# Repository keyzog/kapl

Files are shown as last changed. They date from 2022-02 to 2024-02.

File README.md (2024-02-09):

# Kapl Keyboard

The Kapl is a split ergonomic keyboard with 70 keys (7x5).
Please read project wiki for details: https://github.com/keyzog/kapl/wiki

**Detailed assembly instructions:** https://keyzog.com/post/kapl-build-guide (RU)

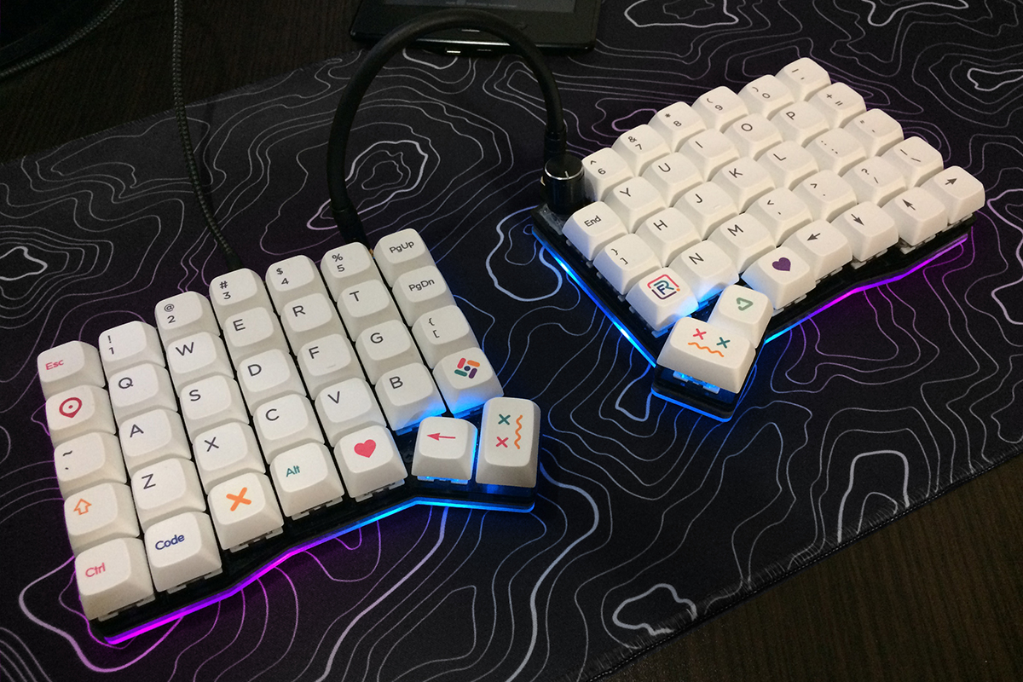
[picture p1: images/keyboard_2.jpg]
Kapl split keyboard

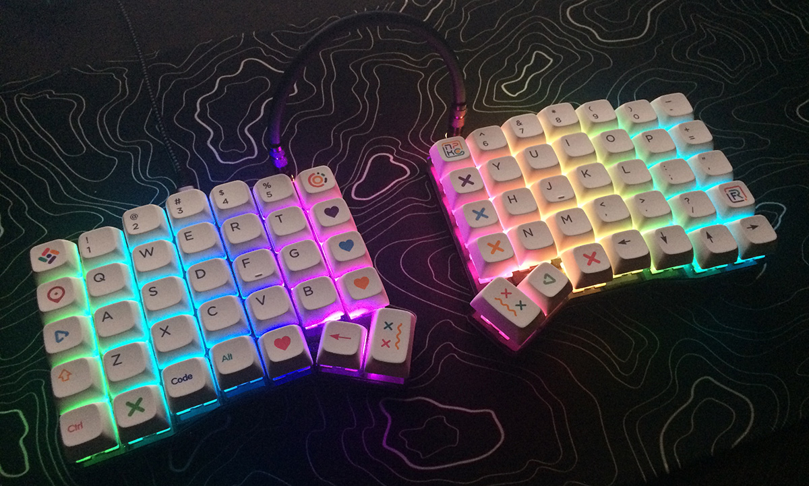
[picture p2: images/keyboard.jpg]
Kapl split keyboard


Board with controller on back side.
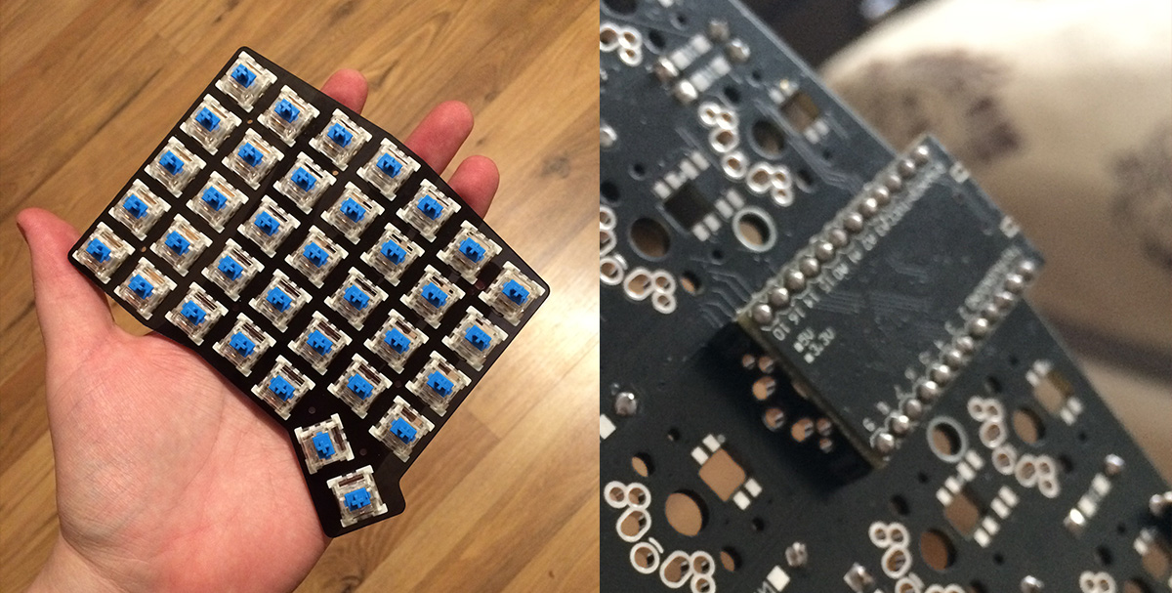
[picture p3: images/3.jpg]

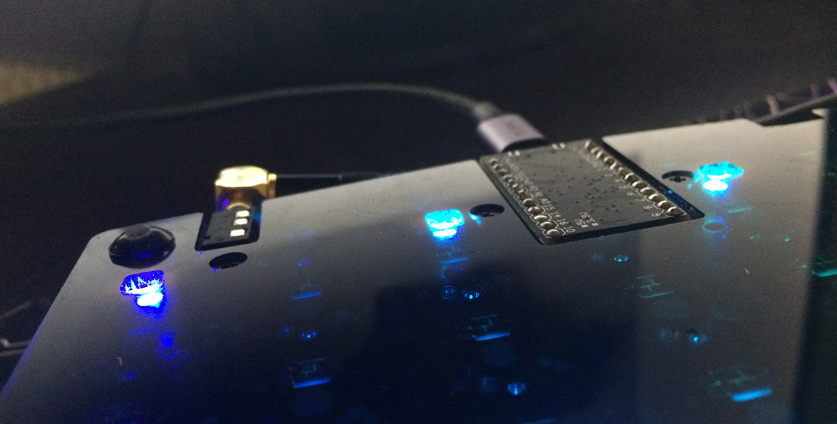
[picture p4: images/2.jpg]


## PCB

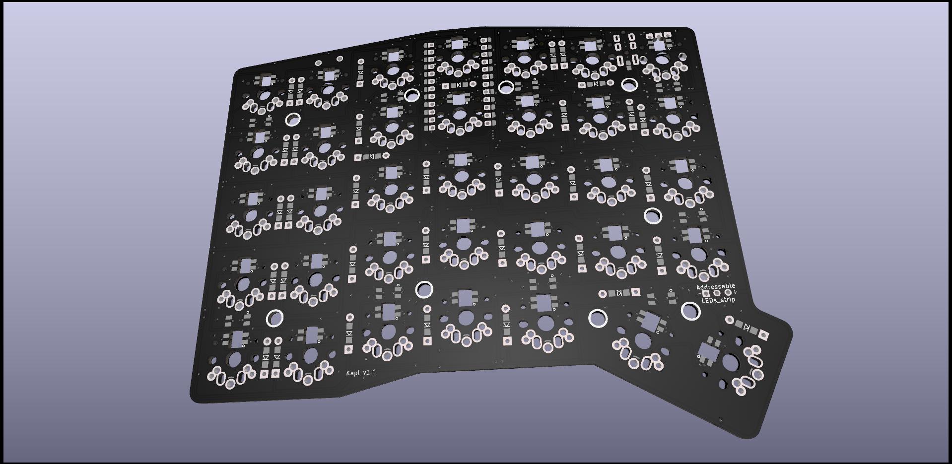
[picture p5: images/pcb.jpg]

[gerbers/gerber\_\_main.zip](https://github.com/keyzog/kapl/raw/main/gerbers/gerber__main.zip)

## Firmware

Kapl uses [QMK firmware](https://qmk.fm/)

## Todo

-  [x] [list of materials](https://github.com/keyzog/kapl/wiki#bill-of-materials)
-  [x] rotation encoder support
-  [ ] building guide
-  [ ] tilting-tenting case

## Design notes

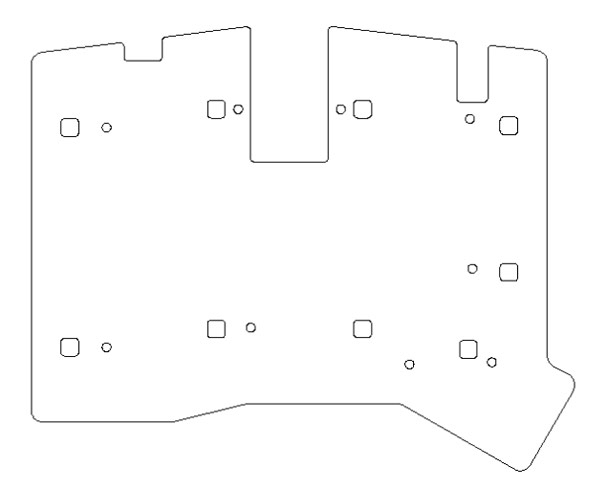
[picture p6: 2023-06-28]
images/case/acrylic/bottom_withLeds_withMKcut.jpg

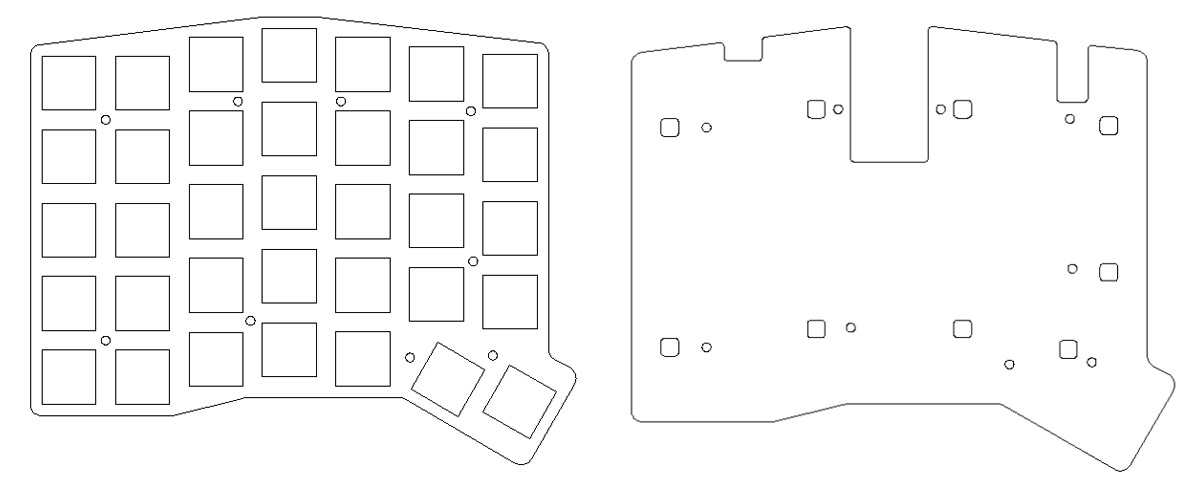
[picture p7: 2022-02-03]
images/case_with_cut.jpg

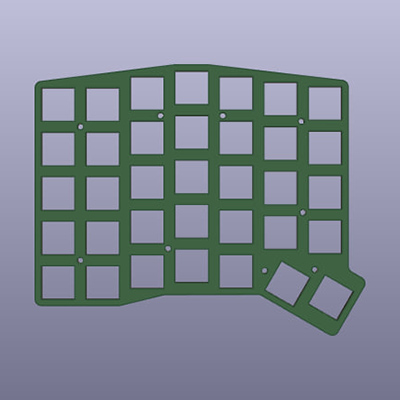
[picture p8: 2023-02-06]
images/case/pcb/top.jpg

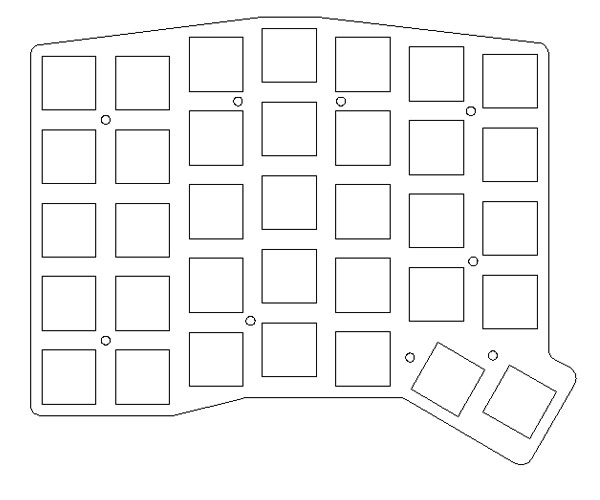
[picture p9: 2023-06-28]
images/case/acrylic/top.jpg

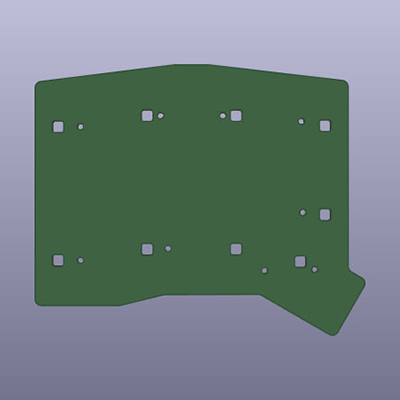
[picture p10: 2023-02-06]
images/case/pcb/bottom_withLeds.jpg

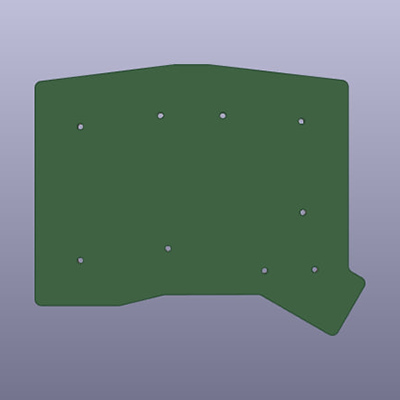
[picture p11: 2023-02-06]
images/case/pcb/bottom.jpg

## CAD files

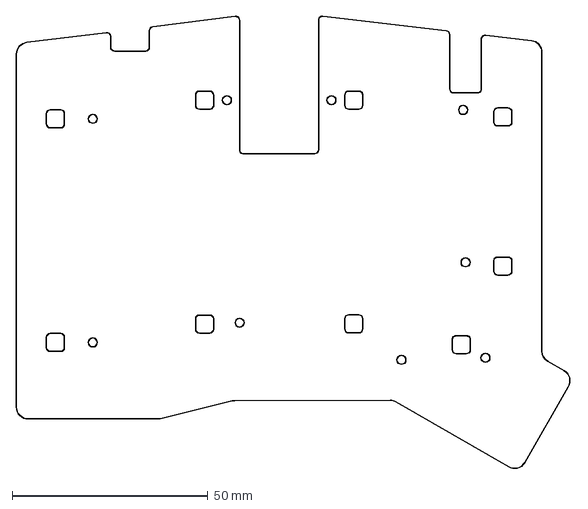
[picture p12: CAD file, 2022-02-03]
case/dxf/bottom_withLeds.dxf
141.9 x 115.7 mm

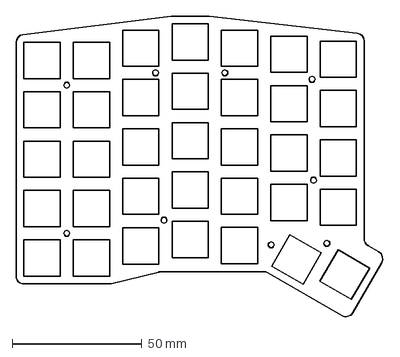
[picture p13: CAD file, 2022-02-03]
case/dxf/top.dxf
141.9 x 116.1 mm

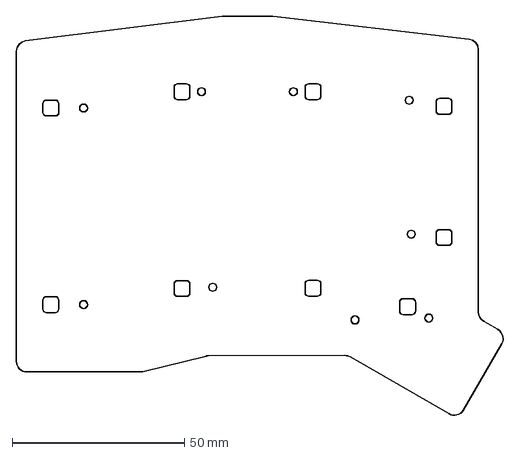
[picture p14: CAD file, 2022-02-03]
case/dxf/bottom_withLeds_withMKcut.dxf
141.9 x 116.1 mm

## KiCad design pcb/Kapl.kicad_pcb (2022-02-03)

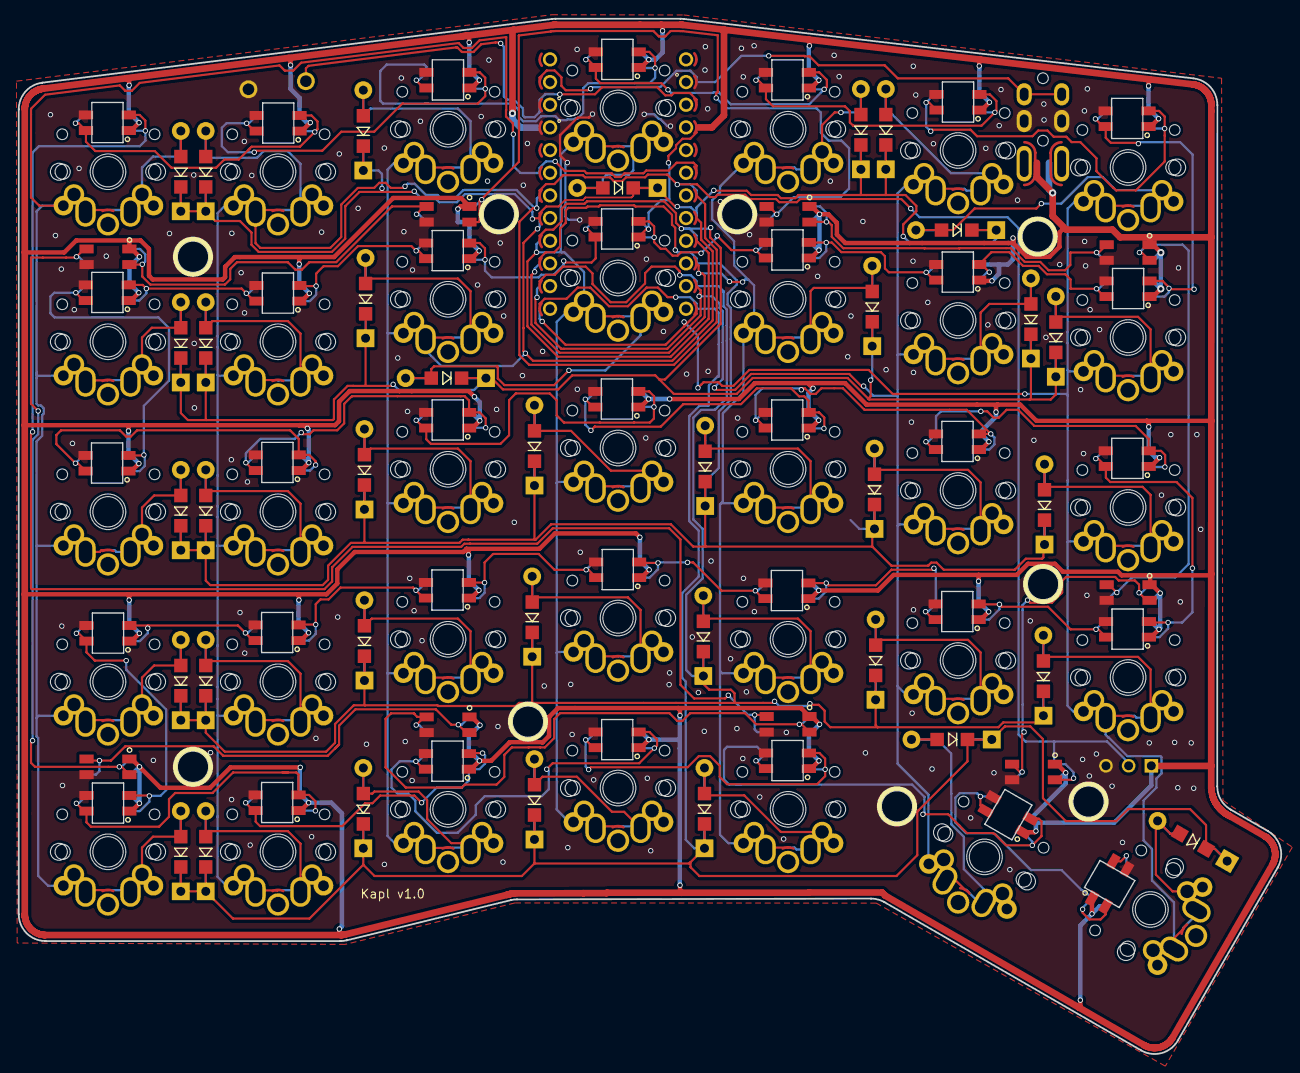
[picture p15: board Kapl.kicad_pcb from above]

Board: 2 copper layers, 141.5 x 116.0 mm, 127 parts (0 on the bottom side), 95 nets.

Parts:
BL1, BL2, BL3, BL4, BL5, BL6, BL7, BL8, BL9: SK6812MINI; SK6812MINI_surface
D1, D2, D3, D4, D5, D6, D7, D8, D9, D10, D11, D12, D13, D14, D15, D16, D17, D18, D19, D20, D21, D22, D23, D24, D25, D26, D27, D28, D29, D30, D31, D32, D33, D34, D35: D; Diode
H1, H2, H3, H4, H5, H6, H7, H8, H9: MountingHole; MountingHole_3.2mm_M3
J1: LED_strip_conector; StripLED_rev
L1, L2, L3, L4, L5, L6, L7, L8, L9, L10, L11, L12, L13, L14, L15, L16, L17, L18, L19, L20, L21, L22, L23, L24, L25, L26, L27, L28, L29, L30, L31, L32, L33, L34, L35: SK6812MINI; SK6812MINI_rev
MJ1: Mini Jack; MJ-4PP-9
RSW1: SW_PUSH; ResetSW
SW1, SW2, SW3, SW4, SW5, SW6, SW7, SW8, SW9, SW10, SW11, SW12, SW13, SW14, SW15, SW16, SW17, SW18, SW19, SW20, SW21, SW22, SW23, SW24, SW25, SW26, SW27, SW28, SW29, SW30, SW31, SW32, SW33, SW34, SW35: SW_PUSH; MX-ALPs-PG1350-rev
U1: ProMicro

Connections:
GND: BL1.2, BL2.2, BL3.2, BL4.2, BL5.2, BL6.2, BL7.2, BL8.2, BL9.2, J1.1, L1.2, L2.2, L3.2, L4.2, L5.2, L6.2, L7.2, L8.2, L9.2, L10.2, L11.2, L12.2, L13.2, L14.2, L15.2, L16.2, L17.2, L18.2, L19.2, L20.2, L21.2, L22.2, L23.2, L24.2, L25.2, L26.2, L27.2, L28.2, L29.2, L30.2, L31.2, L32.2, L33.2, L34.2, L35.2, MJ1.C, RSW1.2, U1.3, U1.4, U1.23
LED: BL1.3, J1.2, U1.7
unnamed: BL1.1, BL2.3
unnamed: BL2.1, BL3.3
unnamed: BL3.1, BL4.3
unnamed: BL4.1, BL5.3
unnamed: BL5.1, BL6.3
unnamed: BL6.1, BL7.3
unnamed: BL7.1, BL8.3
unnamed: BL8.1, BL9.3
unnamed: BL9.1, L1.3
unnamed: D1.2, SW1.2
unnamed: D2.2, SW2.2
unnamed: D3.2, SW3.2
unnamed: D4.2, SW4.2
unnamed: D5.2, SW5.2
unnamed: D6.2, SW6.2
unnamed: D7.2, SW7.2
unnamed: D8.2, SW8.2
unnamed: D9.2, SW9.2
unnamed: D10.2, SW10.2
unnamed: D11.2, SW11.2
unnamed: D12.2, SW12.2
unnamed: D13.2, SW13.2
unnamed: D14.2, SW14.2
unnamed: D15.2, SW15.2
unnamed: D16.2, SW16.2
unnamed: D17.2, SW17.2
unnamed: D18.2, SW18.2
unnamed: D19.2, SW19.2
unnamed: D20.2, SW20.2
unnamed: D21.2, SW21.2
unnamed: D22.2, SW22.2
unnamed: D23.2, SW23.2
unnamed: D24.2, SW24.2
unnamed: D25.2, SW25.2
unnamed: D26.2, SW26.2
unnamed: D27.2, SW27.2
unnamed: D28.2, SW28.2
unnamed: D29.2, SW29.2
unnamed: D30.2, SW30.2
unnamed: D31.2, SW31.2
unnamed: D32.2, SW32.2
unnamed: D33.2, SW33.2
unnamed: D34.2, SW34.2
unnamed: D35.2, SW35.2
unnamed: L1.1, L2.3
unnamed: L2.1, L3.3
unnamed: L3.1, L4.3
unnamed: L4.1, L5.3
unnamed: L5.1, L6.3
unnamed: L6.1, L7.3
unnamed: L8.3, L9.1
unnamed: L9.3, L10.1
unnamed: L10.3, L11.1
unnamed: L11.3, L12.1
unnamed: L12.3, L13.1
unnamed: L13.3, L14.1
unnamed: L7.1, L14.3
unnamed: L15.1, L16.3
unnamed: L8.1, L15.3
unnamed: L16.1, L17.3
unnamed: L17.1, L18.3
unnamed: L18.1, L19.3
unnamed: L19.1, L20.3
unnamed: L20.1, L21.3
unnamed: L21.1, L28.3
unnamed: L22.1, L29.3
unnamed: L22.3, L23.1
unnamed: L23.3, L24.1
unnamed: L24.3, L25.1
unnamed: L25.3, L26.1
unnamed: L26.3, L27.1
unnamed: L27.3, L28.1
unnamed: L29.1, L30.3
unnamed: L30.1, L31.3
unnamed: L31.1, L32.3
unnamed: L32.1, L33.3
unnamed: L33.1, L34.3
unnamed: L34.1, L35.3
VCC: BL1.4, BL2.4, BL3.4, BL4.4, BL5.4, BL6.4, BL7.4, BL8.4, BL9.4, J1.3, L1.4, L2.4, L3.4, L4.4, L5.4, L6.4, L7.4, L8.4, L9.4, L10.4, L11.4, L12.4, L13.4, L14.4, L15.4, L16.4, L17.4, L18.4, L19.4, L20.4, L21.4, L22.4, L23.4, L24.4, L25.4, L26.4, L27.4, L28.4, L29.4, L30.4, L31.4, L32.4, L33.4, L34.4, L35.4, MJ1.D, U1.21
col0: SW1.1, SW8.1, SW15.1, SW22.1, SW29.1, U1.19
col1: SW2.1, SW9.1, SW16.1, SW23.1, SW30.1, U1.18
col2: SW3.1, SW10.1, SW17.1, SW24.1, SW31.1, U1.17
col3: SW4.1, SW11.1, SW18.1, SW25.1, SW32.1, U1.16
col4: SW5.1, SW12.1, SW19.1, SW26.1, SW33.1, U1.15
col5: SW6.1, SW13.1, SW20.1, SW27.1, SW34.1, U1.14
col6: SW7.1, SW14.1, SW21.1, SW28.1, SW35.1, U1.13
data: MJ1.B, U1.2
reset: RSW1.1, U1.22
row0: D1.1, D2.1, D3.1, D4.1, D5.1, D6.1, D7.1, U1.8
row1: D8.1, D9.1, D10.1, D11.1, D12.1, D13.1, D14.1, U1.9
row2: D15.1, D16.1, D17.1, D18.1, D19.1, D20.1, D21.1, U1.10
row3: D22.1, D23.1, D24.1, D25.1, D26.1, D27.1, D28.1, U1.11
row4: D29.1, D30.1, D31.1, D32.1, D33.1, D34.1, D35.1, U1.12

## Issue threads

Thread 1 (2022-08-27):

Cool stuff man, does it support low profile kailh keyswitch?

jmnguye, 2022-08-27:

keyzog, 2022-08-27:
Thank you! Yes it support.

But, keep in mind that spacing between switches is 19.1mm this is MX spacing. This is suitable for most keycaps (lowprofile too). But, if you are going to use MBK keycaps (17.5x16.5mm), then there will be an increased gap between them.

I have a plan make new pcb with spacing for MBK keycaps, but now don't have time for that.

Closed 2023-01-31.

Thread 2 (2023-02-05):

Kailh sockets and recommended version

isavcic, 2023-02-05:
Hello,

Great looking keyboard, thanks for sharing it!

A couple of questions:

- Does the PCB support Kailh hotswap sockets?
- What is the recommended version, the one from the main branch or the revised one?

Thanks!

keyzog, 2023-02-05:
Hello, thanks)
- in now pcb don't support hotswap. I have plan add hotswap, but not before a couple of months.
-  it's better to use the main branch version. I haven't tried soldering version 1.1 yet (pcb_rev branch). You can try it if you want, but at your own risk. But you can safely use [gerber__plate_bottom.zip](https://github.com/keyzog/kapl/blob/pcb_rev/gerbers/gerber__plate_bottom.zip) and [gerber__plate_top.zip](https://github.com/keyzog/kapl/blob/pcb_rev/gerbers/gerber__plate_top.zip) from the pcb_rev branch to create the case.

keyzog, 2023-02-06:
**Remark to previous comment**

Added case pcbs in main branch, should have done it much sooner.
https://github.com/keyzog/kapl/wiki#from-pcb

And moved pcb v1.1 to dev branch, using also at your own risk.

isavcic, 2023-02-11:
Thank you!

Closed 2023-02-11.

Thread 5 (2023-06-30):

how to solder pro micro.

logicalbhanu, 2023-06-30:
Hi, thanks for this great project, i am trying to build it, but being noob in electrical stuff wouldn't be able to figure out how to solder the pro micro, as it is solder on the back of the pcb, with switches on on top it(on front side), can share some pictures of give some suggestion on how to do it.

keyzog, 2023-06-30:
Hello! Hope this helps you: https://imgur.com/gallery/7m69tiw

If you have any questions, you can write to me at the contacts in my profile.

Don't forget to share a photo of the result 😉

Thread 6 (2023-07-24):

no of m2 spacers

logicalbhanu, 2023-07-24:
hi, keyzog
me again(thanks for resolving my last issue), i want to know that in the list of materials you have mentioned the number of spacers as 18, but in the build guides one of the image, i am seeing only 9 spacers, here is the image
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
am i missing something(being a noob in this).

logicalbhanu, 2023-07-26:
thanks mate,my bad i didn't consider the left hand.

Closed 2023-07-26.

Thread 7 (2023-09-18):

what other spacer/standoffs sizes are compatible

logicalbhanu, 2023-09-18:
Hi,
My issue is i am not getting m2 spacer nearby and nor on online at least in my country at good price, can i use m3 spacer or m2.5 spacer, or what are the other options regarding sizes for spacers if possible?

keyzog, 2023-09-20:
Hello!
The size of the hole in the board to accommodate the standoffs is 3.5mm. Only M2 of a standoffs will fit into such a hole.

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

You can save money by using regular M2 bolts and nuts. Just calculate the height of the bolts so that they are not too long. This method is not as convenient compared to racks.

You can also use spacers made of different materials. For example, print on a 3D printer or wrap some [duct tape))](https://live.staticflickr.com/8160/7214525854_733237dd83_z.jpg)

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

Be careful, the very first version of the board had 3.2mm holes; if you ordered the board more than a year ago, you may have this version.

logicalbhanu, 2023-10-22:
i eventually get the m2 spacer/standoff so order it,

but here i am with a new issue and that is, i am try to test the working of some keys before soldering all of them, thus i perform the following tasks:
1. solder all the diodes.
2. flash the pro micros with kapl_v1.hex file given in the link of the repo( i do test my pro connecting two of its pins on opposite sides and they are printing something on my device terminal app).
3. fit all the keys to the top plate and set it with pcb.
4. solder one key among all the keys to test whether it is working or not.

but sadly i am not getting any character when pressing that key, i also tried the reset button and that also seems to be not working( what i am doing is, why reflashing my pro micro rather than shorting the GND and RST pins i am pressing the reset button in the hope that it will start the flash in the qmk toolbox app like it did if shorted the pins directly but nothing is happening there).

i don't know what i am doing wrong so here is the picture of my setup

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

the circled key is the one i have souldered to test the pcb(i order the pcb for jlpcb so i am expecting it of good quality).
so once again can you guide toward any pointer which can help me figure out.

keyzog, 2023-10-22:
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

1) This pin look bad soldered. If the contact is poor, the switches will operate very unstable.
2) You missed one diode.
3) Did you remember to solder the diode under the controller?

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

For just testing pcb you can use tweeters. This is not very convenient, but it is much easier than soldering each switch for testing. https://www.youtube.com/shorts/-FCV9InV3x8

It’s better to write to me in telegram or email, it will be more productive. Contacts are in the profile.

logicalbhanu, 2023-10-23:
thanks again, yes i soldered the diode(it is not visible though because of the pro micro), but yes i do missed the second diode that you pointed out(thanks again), and also thanks for the telegram info it will be much helpfull for me.

Closed 2023-10-23.

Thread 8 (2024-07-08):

Some keys are not working, dunno how to debug

jorgelrezende, 2024-07-08:
Hello, I've finished to assemble on half of my keyboard, but some keys are not working, my question is, all keys only work when the two halfs are assembled together? or each half should work all keys independently?

keyzog, 2024-07-08:
Hello! Some buttons are responsible for switching layers. When you click on them, it may seem that nothing happens, because... Most keyboard testing programs/sites cannot detect such keystrokes.

Below is a screenshot with these buttons:
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

jorgelrezende, 2024-07-08:
right, but all the esc column is not work here on testing, the 5 key and backspace as well, i will try to  verify with a multimeter if all diodes are working, but i dont know what is happening

keyzog, 2024-07-08:
If the entire column does not work, it may be due to poor contact on the microcontroller pin. Make sure it is well soldered.
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

When one button in col/row does not work, it is most likely due to poor soldering of the button legs. In second place, the problem may be in the wrong direction of the diode next to the button.

you can write to me in telegram and send me a photo of the board
https://t.me/keyzog

jorgelrezende, 2024-07-08:
Right, i will verify it, thank you for the help

Closed 2025-01-15.

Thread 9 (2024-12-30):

Can we make the switches hot swappable?

arun-cm, 2024-12-30:

keyzog, 2025-01-04:
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
There's not enough space under the controller to fit a hotswap socket.

PineappleSnackz, 2025-05-06:
Maybe the rest could still be hotswap? Even if just a few need soldering, wouldn't it make swapping switches easier?

ISO-B, 2025-09-22:
Would something like https://www.aliexpress.com/item/1005009260905480.html that work for hot swapping?

Closed 2025-01-15.

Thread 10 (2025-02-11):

right Site  keyboard not working

jorgeluisrezende, 2025-02-11:
hello, i fisnished the keyboard assemble but I have one problem, my right sid is not working. I do not know if i flashed wrong, I flashed both sides arduinos, or if the problem is my cable, I've tested my cable with a multimeter and all  lins of the connector is working well, can your help me to solve this question?

jorgeluisrezende, 2025-02-11:
Found the problem

Closed 2025-02-11.

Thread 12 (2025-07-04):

Support for ZMK

LittlePlanlessFool, 2025-07-04:
Hello! I am currently building a Kapl and want to use it wirelessly with a nice!nano. This requires the use of ZMK. If you give me your permission, I would gladly work on getting ZMK to support this board.

keyzog, 2025-07-10:
Hello, thanks for your interest in the Kapl - really appreciate it!

Sure, go ahead - feel free to work on ZMK support for the board.

You might find my previous work (for the NRFmicro controller) useful as a starting point:

- https://github.com/keyzog/zmk/tree/kapl
- https://github.com/keyzog/kapl-ble-zmk-config

Let me know if you run into any questions!

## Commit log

2023-02-06 Pcb rev (#3)
    * update pcb v1.1
    - added rotation encoder support
    - changed controller's jumpers
    * add bottom and top plates
    * add new gerbers
    * little changes in pcbs
    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
    [Kapl-B_Cu.gbl, Kapl-B_Mask.gbs, Kapl-B_Paste.gbp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]
2023-02-06 change path to pcb gerber
2023-06-28 update pcb to v1.1
    [Kapl.kicad_sch, Kapl.sch]
2023-06-28 add images for Acrylic Case
2023-06-28 update leds_pins image
2023-06-28 move dxf files in case dir
    [bottom.dxf, bottom_withLeds_withMKcut.dxf, top.dxf]
2023-06-28 rename bottom dxf file
    [bottom_withLeds.dxf]
2023-06-28 add leds strip image
2023-06-28 update pcb image
